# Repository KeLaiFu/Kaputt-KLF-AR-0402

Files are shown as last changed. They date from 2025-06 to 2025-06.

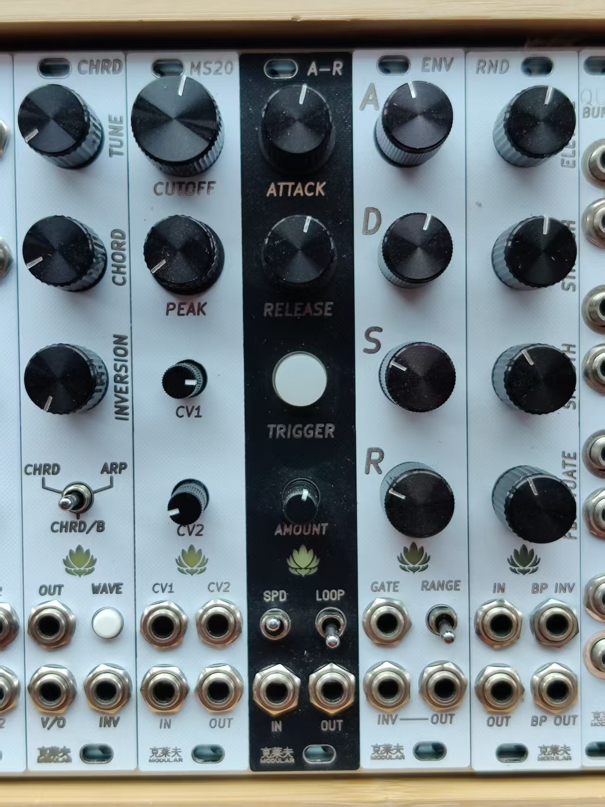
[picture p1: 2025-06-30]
Weixin Image_20250630180554.jpg

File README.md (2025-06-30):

Rework of Kaputtpanzers 6HP eurorack AR module. My version shaves off 2HP and combines the originals LED and button into one unit. 
This version uses 0402 components and is very cheap to get assembled at jlcpcb as all the parts are from the basic component range. 

note* I havn't use the exact assembly files posted here, so double check them if you intend to use them.
It's not really suited for hand soldering due to the tiny pitch of 0402.

Panel should be fabricated in FR4 due to the illuminated logo.

Module is fully tested and working, No further revision are planned.

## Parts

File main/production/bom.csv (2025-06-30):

Designator | Footprint | Quantity | Value | LCSC Part #
C1, C4 | 000_7,5MM_FOIL_STANDARD | 2 | 100N
C2 | CP_Elec_5x5.4 | 1 | 2U2
C3, C5 | CP_Elec_5x5.4 | 2 | 10U
D1 | D_SOD-323_HandSoldering | 1 | 5817
D2, D3 | D_SOD-323_HandSoldering | 2 | bat85
D4, D5 | D_SOD-323_HandSoldering | 2 | 4148
R1, R11, R4 | 0402 | 3 | 22K
R10 | 0402 | 1 | 2K2
R12, R13, R2 | 0402 | 3 | 10K
R16, R7 | 0402 | 2 | 4K7
R3, R8 | 0402 | 2 | 100k
R5 | 0402 | 1 | 220R
R6 | 0603 | 1 | 82K
S2 | sm_SPDT_rec_lug.2 | 1 | LOOP
S3 | sm_SPDT_rec_lug.2 | 1 | TIME
SV1 | EURO_PWR_HEADER_LOCK | 1 | POWER
U$1 | thonkiconn_offset | 1 | GATE
U$2 | thonkiconn_offset | 1 | OUT
U1, U2 | SOP-8_3.76x4.96mm_P1.27mm | 2 | LM358
VR1, VR2 | Potentiometer_Alpha_RD901F-40-00D_Single_Vertical_centered | 2 | 500K
VR3 | Potentiometer_Alpha_RD901F-40-00D_Single_Vertical_centered | 1 | 100K

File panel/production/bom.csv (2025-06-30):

Designator | Footprint | Quantity | Value | LCSC Part #
_11, _3 | 7bca3f90-dd57-426b-b790-816b81f408db | 2
_10, _9, _8, _7, _6, _5, _4, _2, |  | 9

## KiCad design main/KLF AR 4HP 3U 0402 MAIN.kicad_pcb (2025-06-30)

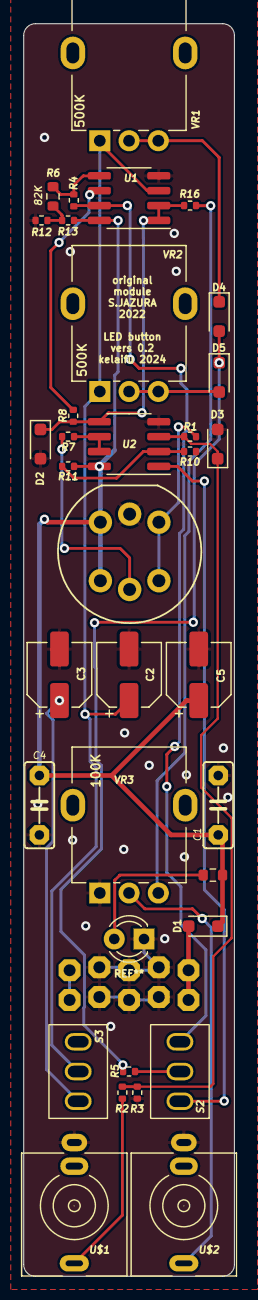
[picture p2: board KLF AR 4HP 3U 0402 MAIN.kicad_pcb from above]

Board: 2 copper layers, 18.0 x 107.0 mm, 33 parts (1 on the bottom side), 22 nets.

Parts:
C1, C4: 100N; 000_7,5MM_FOIL_STANDARD
C2: 2U2; CP_Elec_5x5.4
C3, C5: 10U; CP_Elec_5x5.4
D1: 5817; D_SOD-323_HandSoldering
D2, D3: bat85; D_SOD-323_HandSoldering
D4, D5: 4148; D_SOD-323_HandSoldering
R1, R4, R11: 22K; R_0402_1005Metric
R2, R12, R13: 10K; R_0402_1005Metric
R3: 100k; R_0402_1005Metric
R5: 220R; R_0402_1005Metric
R6: 82K; R_0603_1608Metric
R7, R16: 4K7; R_0402_1005Metric
R8: 100K; R_0402_1005Metric
R10: 2K2; R_0402_1005Metric
S2: LOOP; sm_SPDT_rec_lug.2
S3: TIME; sm_SPDT_rec_lug.2
SV1: POWER; EURO_PWR_HEADER_LOCK
U1, U2: LM358; SOP-8_3.76x4.96mm_P1.27mm
U$1: GATE; thonkiconn_offset
U$2: OUT; thonkiconn_offset
VR1, VR2: 500K; Potentiometer_Alpha_RD901F-40-00D_Single_Vertical_centered
VR3: 100K; Potentiometer_Alpha_RD901F-40-00D_Single_Vertical_centered

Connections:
GND: C1.2, C2.2, C3.2, C4.2, C5.2, D2.2, D3.2, R3.1, R10.1, R12.1, SV1.GND1, SV1.GND2, SV1.GND3, SV1.GND4, SV1.GND5, SV1.GND6, U1.4, U2.4, U$1.GND, U$2.GND, VR3.1
unnamed: D1.2, SV1.POS1, SV1.POS2
unnamed: SV1.NEG1, SV1.NEG2
unnamed: U$2.P$1, VR3.2
unnamed: R16.2, VR3.3
unnamed: R7.2, U2.6, U2.7
unnamed: D3.1, R1.1, R2.2, R3.2, U2.3
unnamed: R2.1, U$1.P$1
unnamed: S2.1, U2.1
unnamed: R4.1, S2.3, U1.7
unnamed: R5.1, S2.2
unnamed: D4.1, VR1.2, VR1.3
unnamed: D4.2, D5.1, R5.2
unnamed: D5.2, VR2.2, VR2.3
unnamed: C3.1, S3.1
unnamed: C2.1, S3.2, U1.3, VR1.1, VR2.1
unnamed: R4.2, R6.1, U1.5
unnamed: R8.2, U1.6
unnamed: D2.1, R8.1, R16.1, U1.1, U1.2, U2.5
VCC: C1.1, C4.1, C5.1, D1.1, R11.2, R13.2, U1.8, U2.8
VCOMP: R10.2, R11.1, U2.2
VREF: R6.2, R12.2, R13.1
